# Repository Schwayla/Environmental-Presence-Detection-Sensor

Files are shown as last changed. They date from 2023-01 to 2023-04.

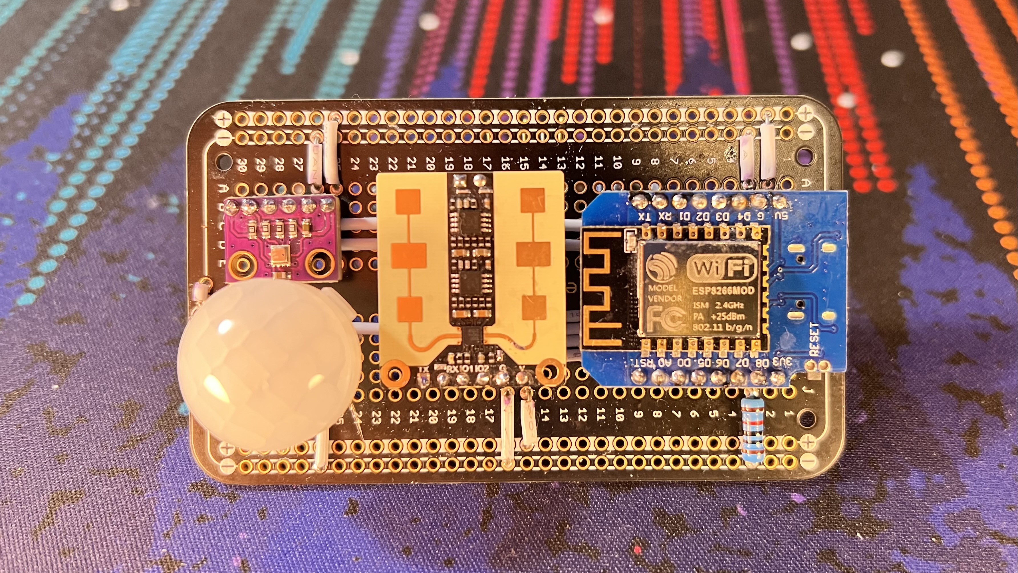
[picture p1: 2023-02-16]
Documents/Photos/sensor_full.jpg

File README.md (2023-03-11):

# Introduction
  - This is a sensor that uses the DFRobot mmWave Sensor, Panasonic PIR Sensor, and BME280 for motion detection and environmental data for use on **ESPHome**. As you may have guessed this was a project inspired by Everything Smart Home's video and subsequent sensor as well as his inspiration igiannakas who made a similar sensor.
  - I am new to coding so this is probably not the best way to code this but it works.
  - I also used PowerPoint to make the diagrams.

sensor_full
  
# Bill of Materials
  - D1 Mini 8266, Type-C (Aliexpress)
  - USB-C to USB-C Cable (Aliexpress)
  - USB-C Charger (I use an ANKER PowerPort III buts that's overkill)
  - DFRobot mmWave Sensor (SEN0395) (I get from DFRobot Store)
  - Panasonic EKMC1603111 (Digi-Key: 255-3086-ND)
  - BME280 (Aliexpress / Amazon)
  - Solid-Core 22AWG wire - 63.5cm / 25in (Aliexpress)
  - 10K Ohm Resistor (Aliexpress / Amazon)
  - ElecrtoCookie Prototyping PCB Board (Amazon)
  
  [BOM Reference](https://github.com/Schwayla/Environmental-Sensor/blob/280037779f692ed72e2192dc8d59334414fc8657/Documents/Materials-Tools/Bill%20of%20Materials)
  
# Tools Needed
  - Safety Glasses
  - Soldering Iron (I like the TS100)
    - Solder
    - Iron Cleaner
    - Brush-on or Liquid Flux
    - Smoke/Fume Filter
  - Hot Glue Gun (I use a Gorilla Glue Hi/Low)
  - Wire strippers
  - Flush-Cut Wire Cutters (Aliexpress or Knipex)
  - Permanent Marker (I use silver)
  - (OPT) Soldering mat or holder
  - (OPT) Breadboard (To test everything first)
  
  [Tools Reference](https://github.com/Schwayla/Environmental-Sensor/blob/9cfe84de354dd05abc04a752588c11a8314ef70a/Documents/Materials-Tools/Mentioned%20Tools)
  
# Software/Programs
  - [Home Assistant](https://www.home-assistant.io/)
  - [ESPHome](https://esphome.io/)
  
# Not Included in this project...
  - The Skills to do the things in this project. YouTube is my best friend when it comes to learning how to do something and it can do a much better job of teaching you the skills needed to make this than I can.
  - I had to look up how to make a README on here so...
  
**Skills Needed**
  - [Soldering](https://youtu.be/6rmErwU5E-k)
  - [Wire Stripping](https://youtu.be/JVJsJ4scCBk)
  - Basic Understanding of Code (I barely know it) 
  - Computer Skills 
    
# How-To Guide
## Setup/Prep
  1. [Setup ESPHome Instance on Home Assistant](https://esphome.io/guides/getting_started_hassio.html) (Just grab it from Add-Ons)
  2. [Load initial software on to the ESP8266 from ESPHome](https://youtu.be/Viqvx7hMMJs)
    - MUST BE DONE BEFORE INSTALLING THE 8266 BOARD ONTO THE PCB/BREADBOARD!
  3. Cut and strip wires - [Wire List](https://github.com/Schwayla/Environmental-Sensor/blob/1f8e7593d6e171ae759ecf0c736d8ca7518d715f/Documents/Diagrams/ElectroCookie_MD_WireList.png) | [Pre-Cut Wires](https://github.com/Schwayla/Environmental-Sensor/blob/2cb97e723ad9acc277df67176590945e9eb55532/Documents/Diagrams/WireList_pre-cut_wires.PNG)

  ElectroCookie_MD_WireList
  
## Fabrication
  1. Solder pins to components.
  
  

   - I like to stick the pins into a breadboard to hold them in place while soldering.

  
  
   - After soldering the pins to the components, slide the pin retainer strips 3mm down away from the component boards. This will help in the installation of the components in the future and allow for clearance over the wires on the board.
  
  
  
  2. solder wires in-place on ElectroCookie Board. [Reference Diagram](https://github.com/Schwayla/Environmental-Sensor/blob/6eeecd7a87b013b7dbf060ae7f8748a2fa184cad/Documents/Diagrams/esp8266_env_sensor_pcb_va.pdf) **(Path: Documents/Diagrams/esp8266_env_sensor_pcb_va.pdf)**
    - Verify all wires are correctly soldered to the specified spot.
    - Visually inspect all solder points and repair as needed.
      
  
  
  ! -- ! -- ! - **Make sure you have loaded the initial software onto the ESP8266 from step 2 of setup / prep** - ! -- ! -- !
  
  3. Solder components to board. [Reference Diagram](https://github.com/Schwayla/Environmental-Sensor/blob/6eeecd7a87b013b7dbf060ae7f8748a2fa184cad/Documents/Diagrams/esp8266_env_sensor_pcb_va.pdf) **(Path: Documents/Diagrams/esp8266_env_sensor_pcb_va.pdf)**

  sensor_full
    - Visually inspect all solder points and repair as needed.
    
  4. Connect board to power (Connect the ESP8266 to the power brick via USB-C cable).
    - Allow around 2 minutes for the board to boot and connect to wifi.
  5. Edit the device in ESPHome and [add the code from this project](https://github.com/Schwayla/Environmental-Sensor/blob/90b6b86ba92d5fca961ce72326073a1cad06f3d1/env-sensor-code.txt) to your device UNDER the existing code that was loaded to the ESP8266 in step 2 of setup / prep. [Code Example](https://github.com/Schwayla/Environmental-Sensor/blob/d74956dccb4689bdeb070d1cdd81721c73e84971/Documents/Photos/Code%20Example.png)
  
  6. Install the code **Wirelessly** and wait for the board to connect (You can watch the progress of the load and the connection via the Logs)
  
  code_install_wireless

   - This will take a few minutes...
  
  7. Home Assistant will automatically recognize the device under **Devices & Services**. You can now configure it and add it to automations and what not.

### Adding Sensor to Automations (I'm only including this because I was confused)
  - When searching for a Device Trigger, search the name of the device ie. Environmental-Sensor (or whatever you named yours) THEN select the sensor as an entity from that device.

HA_Sensor_Add_Trigger

### Using a BMP280 instead of BME280

Replace the BME280 code with the following under #sensor

    #Sensor BMP280
    - platform: bmp280
     temperature:
        name: "BMP280 Temperature"
       oversampling: 16x
       id: bmp280_temperature
     pressure:
       name: "BMP280 Pressure"
       id: bmp280_pressure
     i2c_id: bus_a  
     address: 0x76
      update_interval: 15s

# References, Guides, & Resources
 - igiannakas's guide: https://github.com/igiannakas/mmwave-d1mini
 - hjmcnew's documentation on mmWave sensors in ESPHome: https://github.com/hjmcnew/esphome-hs2xx3a-custom-component/tree/release
 - Everything Smart Home's Video: https://youtu.be/Viqvx7hMMJs
 - crlogic Home Assistant Forum Post: https://community.home-assistant.io/t/mmwave-presence-detection-esphome-style/382778
 - ESPHome's Main Site: https://esphome.io/
   - ESP8266: https://esphome.io/components/esp8266.html
   - UART: https://esphome.io/components/uart.html
   - BME280: https://esphome.io/components/sensor/bme280.html
   - PIR Sensor: https://esphome.io/cookbook/pir.html
   - mmWave Sensor: It is programmed via UART, but on this current build it is treated as a Binary Sensor. No ESPHome Docs yet
   
### Look at you! Makin' some cool stuff...You're AWESOME!!

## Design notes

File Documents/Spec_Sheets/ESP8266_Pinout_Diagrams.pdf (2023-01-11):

ESP8266 WeMos D1 Mini Pinout

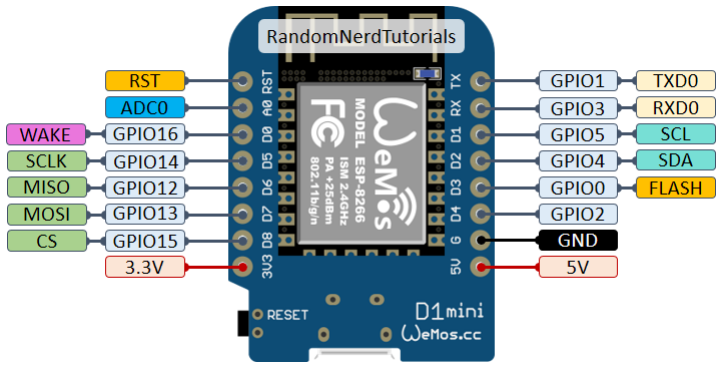
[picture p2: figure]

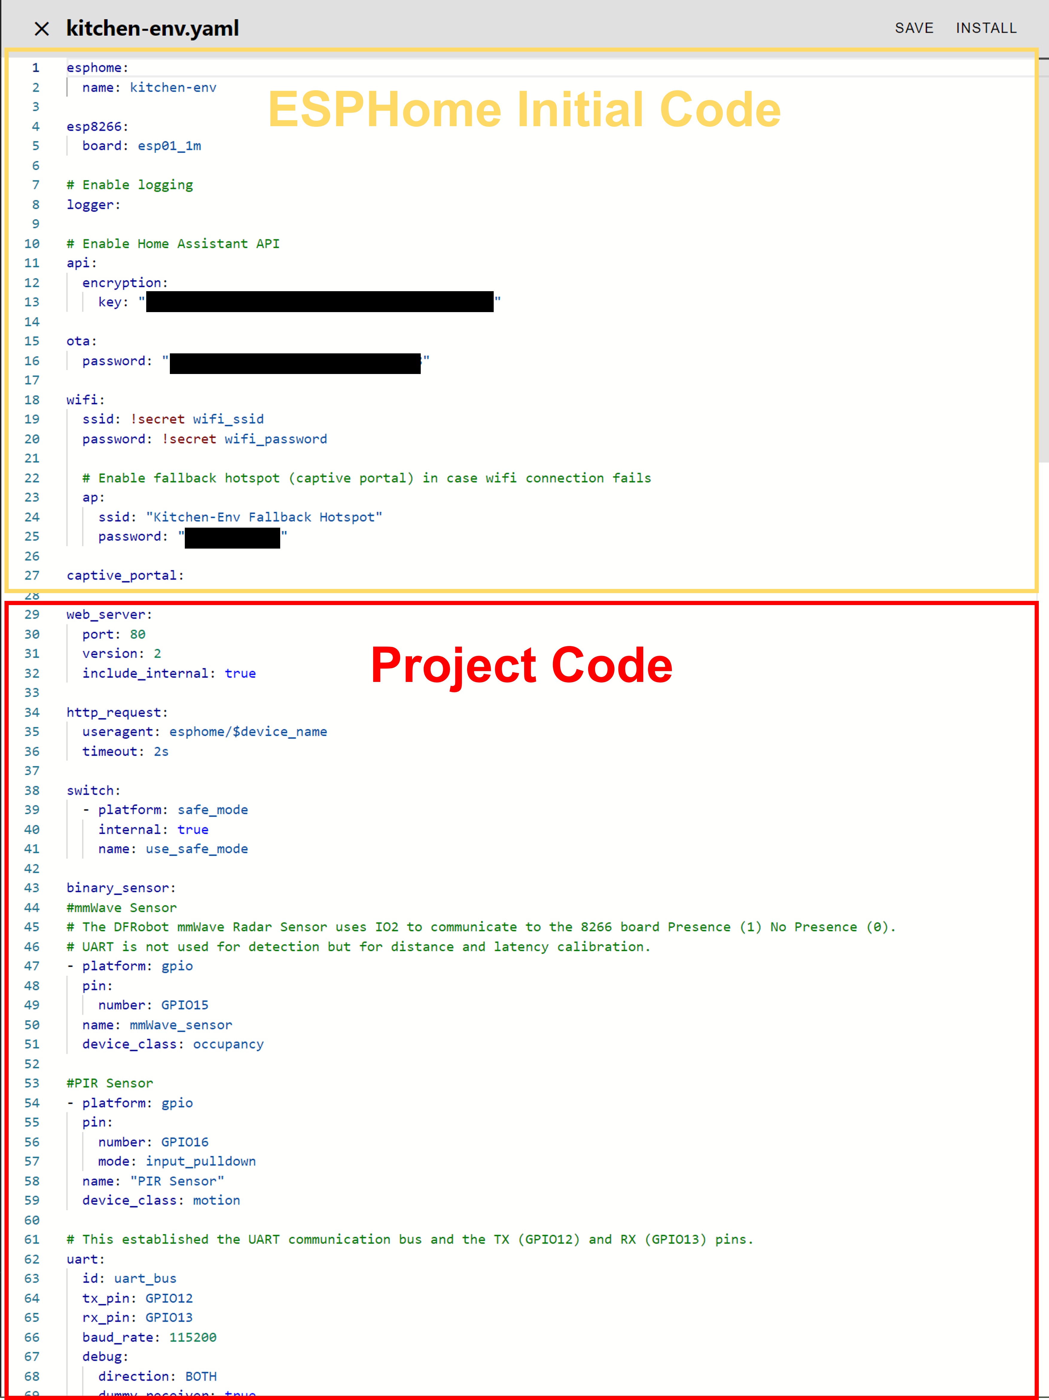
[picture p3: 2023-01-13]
Documents/Photos/Code Example.png

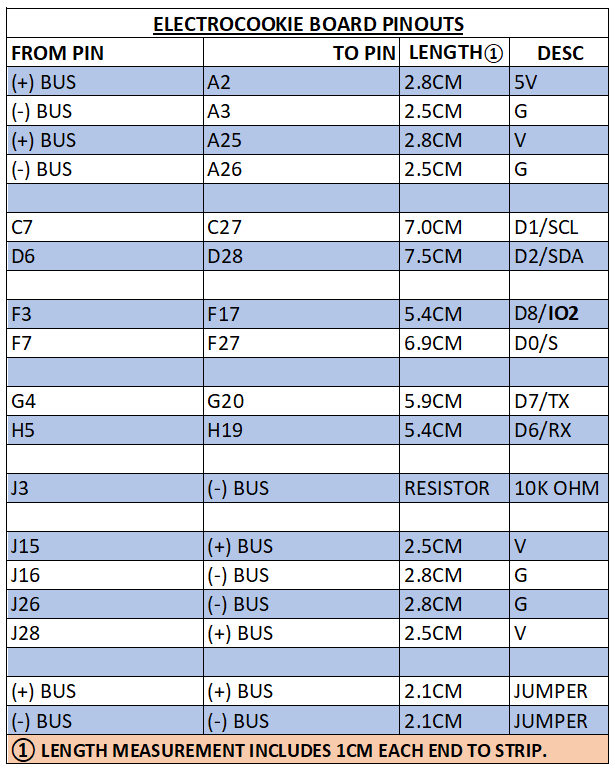
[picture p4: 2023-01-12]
Documents/Diagrams/ElectroCookie_MD_WireList.png

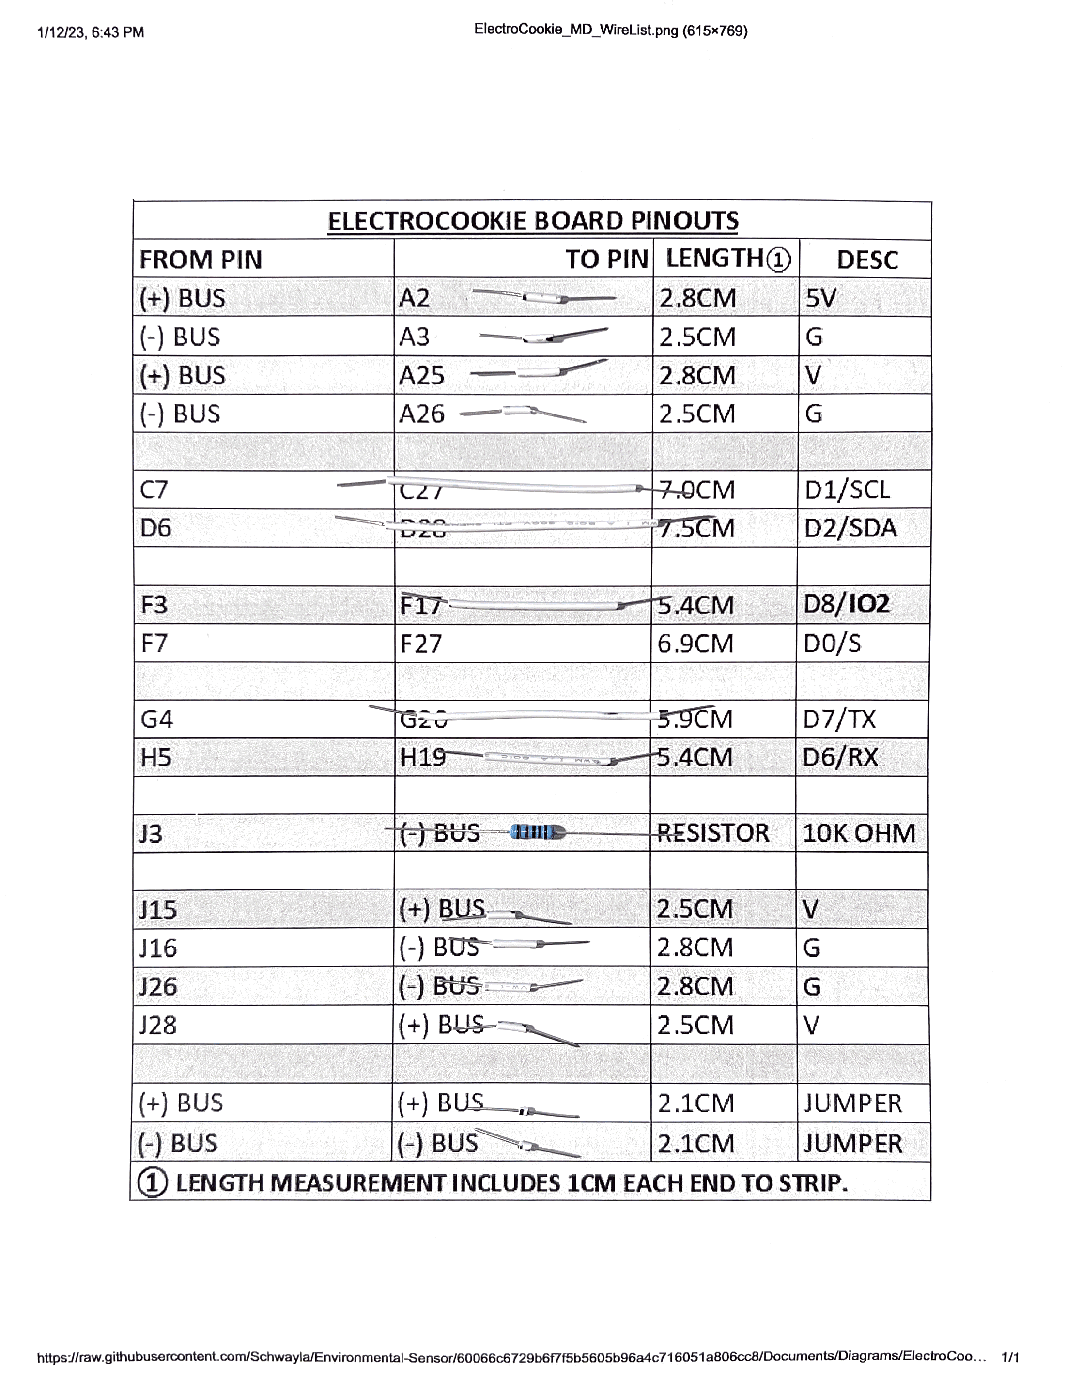
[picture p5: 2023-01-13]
Documents/Diagrams/WireList_pre-cut_wires.PNG

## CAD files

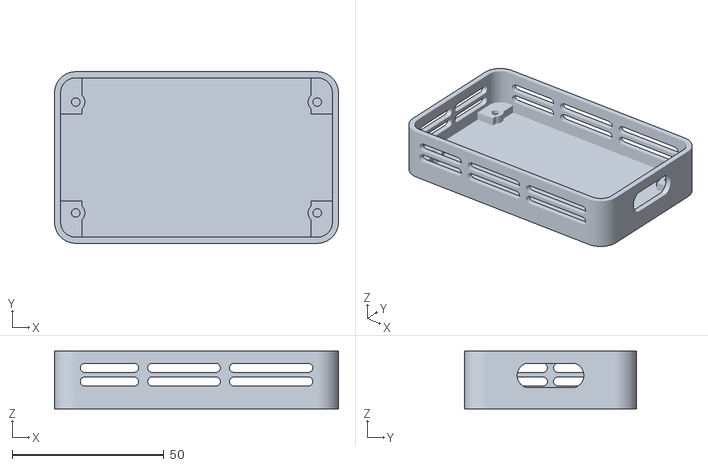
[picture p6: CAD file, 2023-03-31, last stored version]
3D Printed Case/ENV Container.stl
93.5 x 56.5 x 19.0

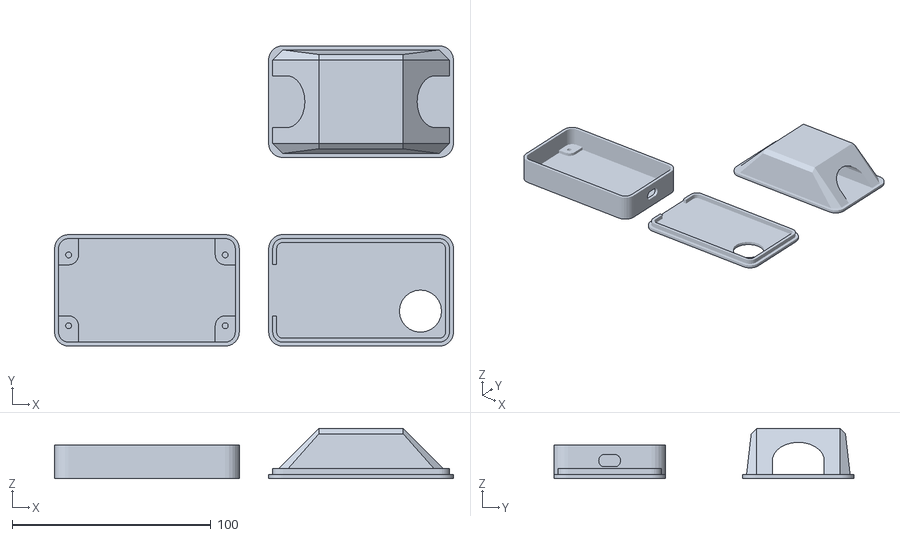
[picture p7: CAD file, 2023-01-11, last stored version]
Documents/3D Printed Case/Env_sensor_case.stl
200.6 x 150.9 x 25.2

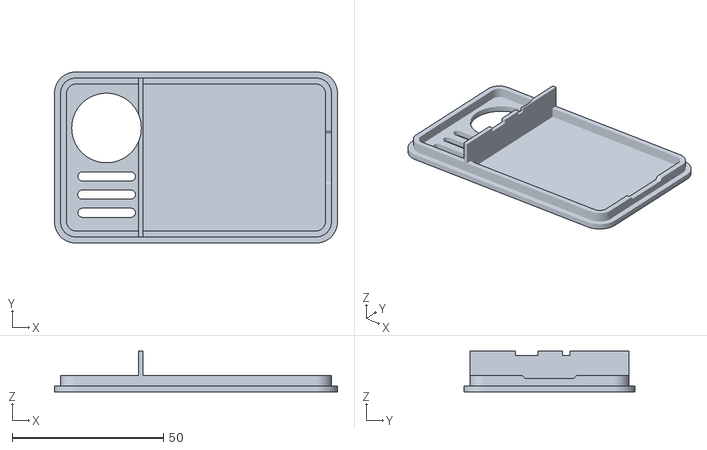
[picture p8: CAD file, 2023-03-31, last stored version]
ENV Lid.stl
93.5 x 56.5 x 13.5

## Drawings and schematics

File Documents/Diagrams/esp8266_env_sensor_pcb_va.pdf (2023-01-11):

5V
G

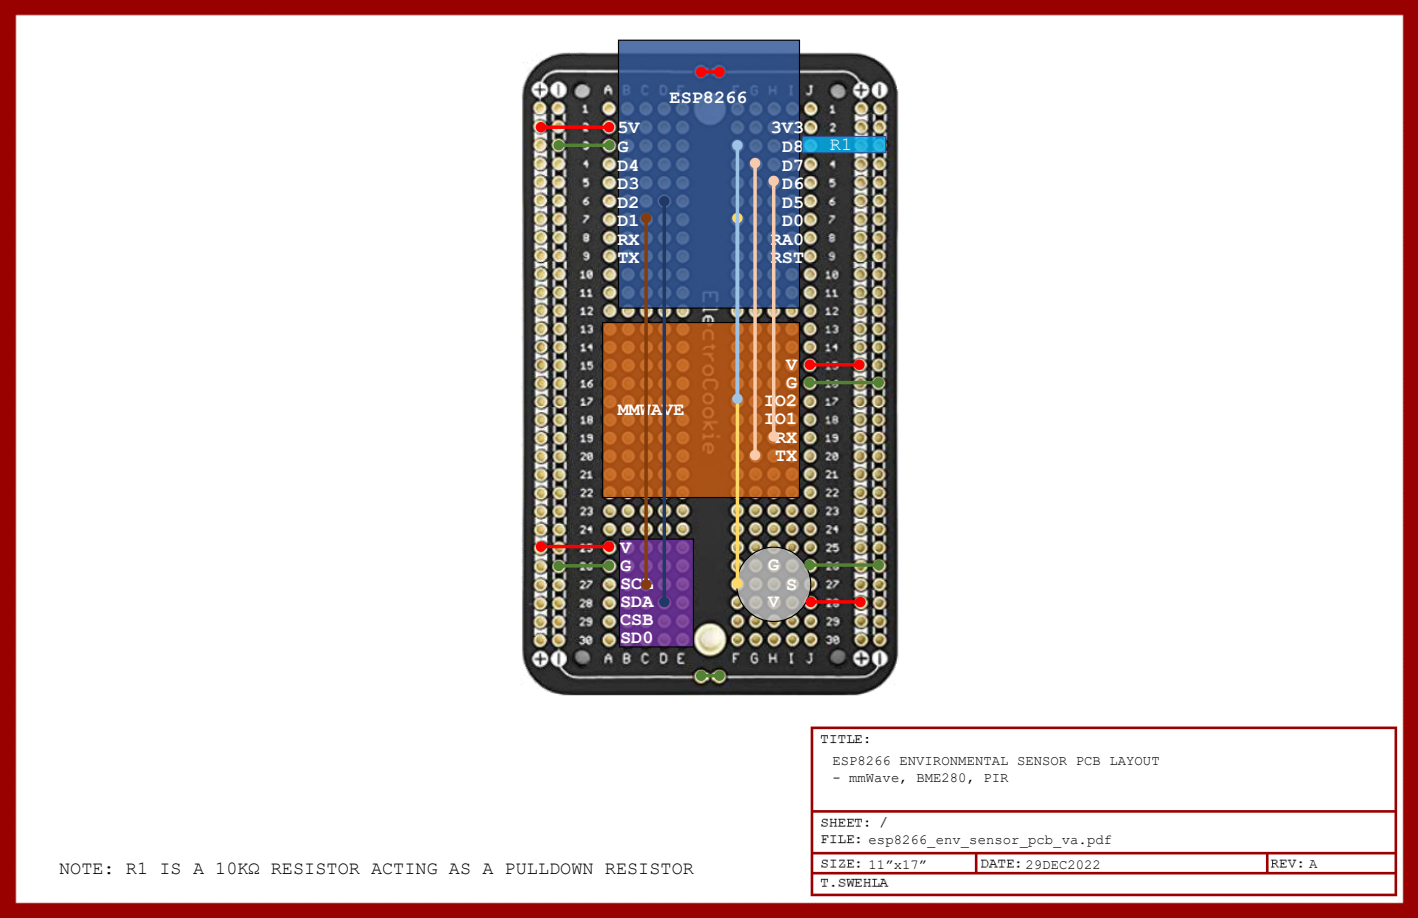
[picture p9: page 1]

ESP8266 ENVIRONMENTAL SENSOR PCB LAYOUT
- mmWave, BME280, PIR

NOTE: R1 IS A 10KΩ RESISTOR ACTING AS A PULLDOWN RESISTOR

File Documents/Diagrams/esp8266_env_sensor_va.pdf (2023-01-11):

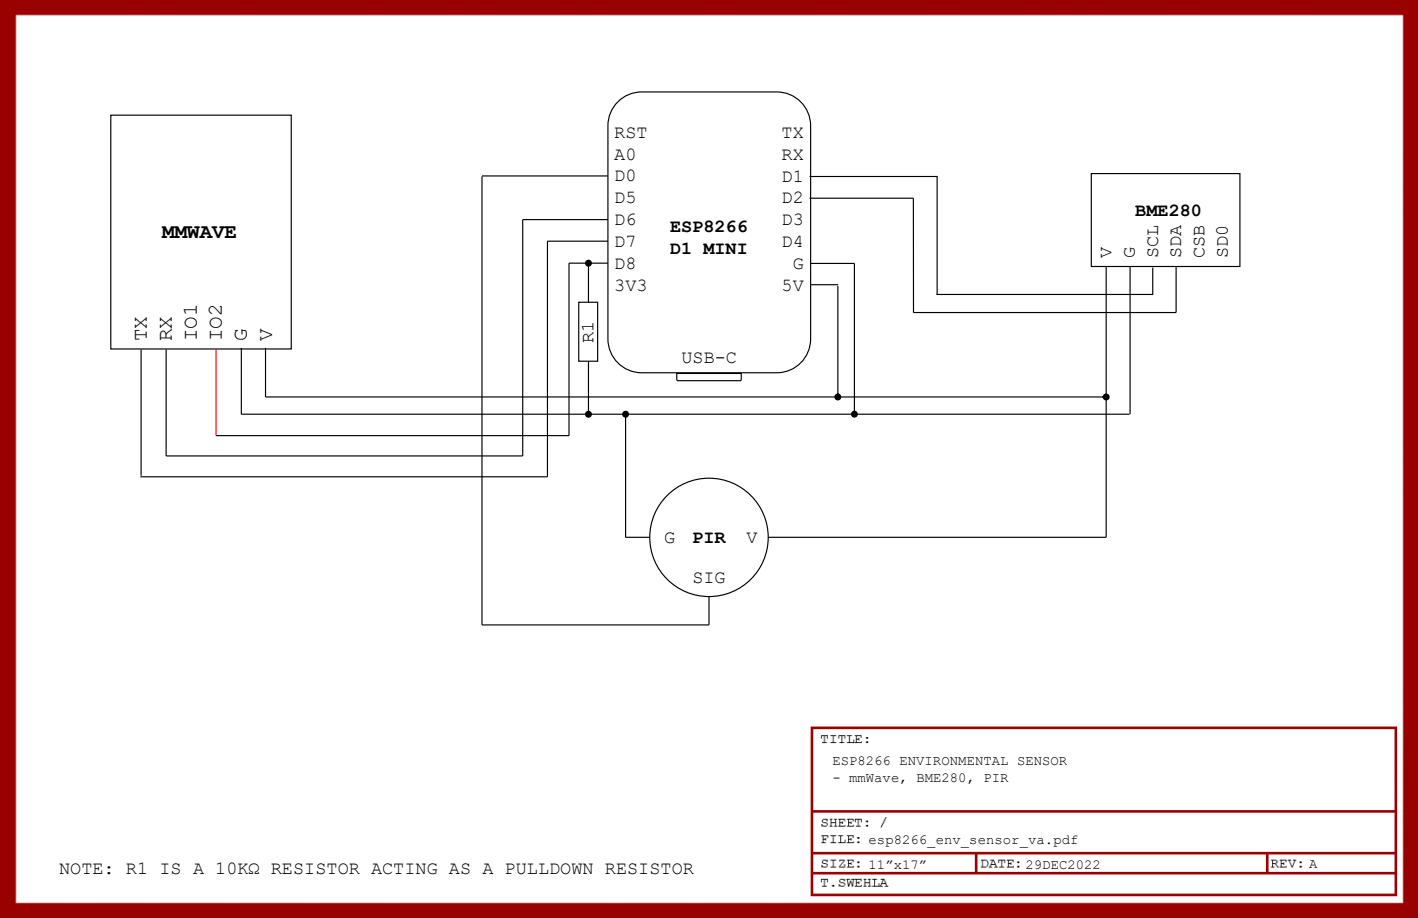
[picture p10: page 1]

NOTE: R1 IS A 10KΩ RESISTOR ACTING AS A PULLDOWN RESISTOR

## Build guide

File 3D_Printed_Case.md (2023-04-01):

# Introduction
This is the case I designed for this Environmental / Presence Detection Sensor. The program I used was OnShape Free, feel free to remix the design to fit your needs. If you have any suggestions for design changes I am open to any suggestions!
## Project Link
https://www.printables.com/model/439260-environmental-sensor-case

# Bill Of Materials (What I used)
  - eSUN PLA+
  - 4x M2 Brass Nut Knurled Threaded Inserts
  - 4x M2x5 Button Head Hex Key Screws

# Tools Needed
  - 3D Printer with at least 100mm x 100mm x 50mm printable area, or a friend with a 3D Printer :)

# How To Guide

# Resources, References, & Guides

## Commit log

2023-01-11 Create BOM
2023-01-11 Update BOM
2023-01-11 Rename BOM to Documents/BOM
    Moved file to Documents Folder
2023-01-11 Rename Documents/BOM to Documents/Materials-Tools/BOM
    created materials-tools folder and moved this file to it
2023-01-11 Rename BOM to Bill of Materials
2023-01-12 Update README.md
    changed WireList permalink to match new list
2023-01-12 Update README.md
    added total wire length needed
2023-01-12 Update Bill of Materials
    added total length of wire needed
2023-01-12 Update README.md
    added BOM Reference link
2023-01-13 Update README.md
    adding wireless install photo
2023-01-13 Update env-sensor-code.txt
    Clarified instructions to paste code
2023-01-13 Update Mentioned Tools
    changed solder link bc the crap from china was crap
2023-02-16 Update README.md
    Added new sensor_full images
2023-03-18 Delete Env_sensor_case.stl
    Incomplete, unfinished file. new one to come
    [Env_sensor_case.stl]
2023-03-31 Add files via upload
    Adding new case STLs
    [ENV Container.stl, ENV Lid.stl]
2023-03-31 Add files via upload
    New case STLs
    [ENV Container.stl, ENV Lid.stl]
2023-03-31 Update and rename filler file to 3D Case Info
    Changed name
2023-04-01 Update 3D Case Info
2023-04-01 Delete env-sensor-code.txt
    central point of download "Releases"
2023-04-01 Delete ENV Lid.stl
    see printables website
    [ENV Lid.stl]
2023-04-01 Delete ENV Container.stl
    See printables website
    [ENV Container.stl]
2023-04-01 Delete 3D Case Info
    changing file type
